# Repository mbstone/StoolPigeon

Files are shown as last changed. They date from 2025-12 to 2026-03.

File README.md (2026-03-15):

# Stool Pigeon
Welcome to the workspace for the open-source project Stool Pigeon. The goal of this project is to create a toilet-mounted device that visually, audibly, and or otherwise monitors bowel movements. 

# Values
* Accessibility 
* Privacy  
* Affordability
* Community 

# What this project needs
* 3D case design
* Board and perpheral design
* Ideas and enthusiasm
* Open-source experience

# What is here
* Some prototype Arduino IDE configuations
* A logging web server used to collect data from device while running and testing
* The Platform IO project used to build the device 
* Some unfinished 3D case designs originally made in Tinkercad

# Project Status
## Progress
* circuit design for basic FSR usage
* connected to wifi
* connected to logging webserver on laptop
* deep sleep woken by button press

## To Do Next
* document hardware layout
* guide for wifi credential deps
* add in image to POST request
* wake from deep sleep with pressure
* add TLS / https

## Future Improvements

## Prototype Picture

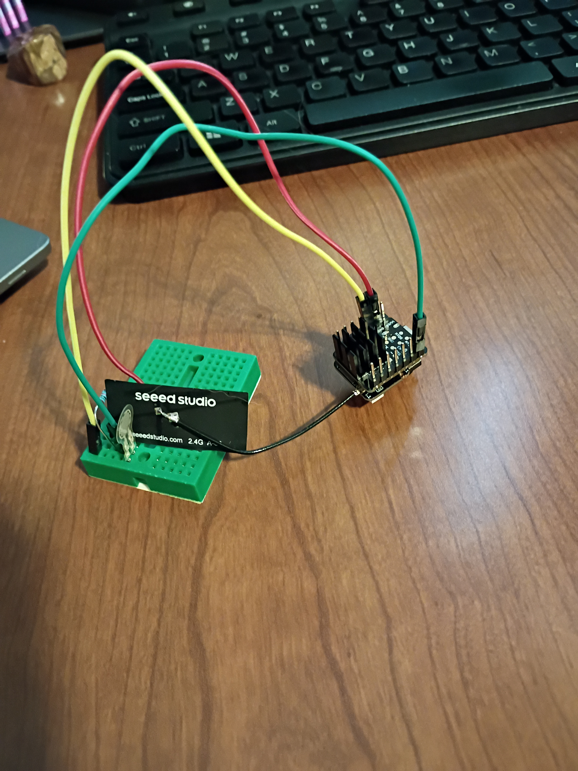
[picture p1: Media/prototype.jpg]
PrototypeSystem


# Notes

## Sketch Uploads
* Correct port only appears after device is plugged in
* open serial monitor manually

## verify / compile errors
* need to install and select XIAO board (SenseS3)

## Force Sensitive Resistors
* Use touch pin to wake
* take reading from FSR to determine seated time and person's identity

## Wifi
* 2.4 Ghz only

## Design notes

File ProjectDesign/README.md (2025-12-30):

# Outerwear
## options
* hanger
* toilet seat
## current selection
* hanger: 
    * strengths: small, no install
    * weakness: physical stability, cleaning
## needs
* allows pressure sensing
* clean easily, brush ideally
* non-invasive
* easy to place and remove
* water-tight
* reasonably priced
* vantage point on bowl

# illumination
## options
* white light LED 
* 500 nm LED with 520-550 emission filter for stool and 600-700 filter for blood
## current selection
* white light LED
    * strengths: cheap, easy hardware, lowest power, presence of training images
    * weakness: detecting blood in edge cases; discrimination of blood and stool
## needs
* bright, stable light source

# network
## options
* toilet device broadcast wifi network, serves images to front end 
* separate server collects images from toilet device client, front end accesses server
## current selection 
* separate server
    * strengths: storage and power, easier to secure, supports multiple users, easier to send data to iPoop central
    * weakness: additional expense, setup overhead, troubleshooting
## needs
* secure
* store data indefinitely
* support analyses of data
* passive data logging and access 

# stool classification algorithm
## options
* MobileNetV2 
* MCUNetV2
## articles
* https://proceedings.mlr.press/v149/zhou21a/zhou21a.pdf
* https://openaccess.thecvf.com/content/CVPR2022W/CVPM/papers/Zhang_Human_Stools_Classification_for_Gastrointestinal_Health_Based_on_an_Improved_CVPRW_2022_paper.pdf
* https://pmc.ncbi.nlm.nih.gov/articles/PMC11350077/

# electronics
## boards
* Seeed Studio XIAO ESP32S3 Sense
    * 102010635-FA
    * OV2640 camera sensor
    * https://wiki.seeedstudio.com/xiao_esp32s3_getting_started/
    * https://mjrovai.github.io/XIAO_Big_Power_Small_Board-ebook/
    * camera pins here: https://github.com/limengdu/SeeedStudio-XIAO-ESP32S3-Sense-camera/blob/main/take_photos/camera_pins.h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
    * core: 
        * ESP32-S3R8
        * Xtensa LX7 dual-core, 32-bit processor up to 240 MHz
* Ardiuno feather huzzah

# system
## webserver
* plugged in
* receives logs from monitor
* serves logs to personal device app
* runs classification models? 
## monitor
* on battery
* deep sleep during inactivity
## personal device
* checks for new data from webserver
* pulls data onto device
* runs classification models?

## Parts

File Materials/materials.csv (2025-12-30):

Product Name | Manufacturer | Purchase Amount | Source | URL | Last Purchased Date | Purpose | Manufacturer ID
Seeed Studio XIAO ESP32S3 Sense (Pre-Soldered) | Seeed Studio | $24.99 | Amazon | https://www.amazon.com/dp/B0DRNW6KMG?ref=ppx_pop_dt_b_product_details&th=1 | Jan 25, 2025 | Toilet-mounted control board with camera, mic, and wifi | 102010635
Thin Film Pressure Sensor | Flexniss | $8.74 | Amazon | https://www.amazon.com/dp/B07T1CHY58?psc=1&ref=ppx_pop_dt_b_product_details | Jan 6, 2025 | Detection of seated user on toilet | DF9-16

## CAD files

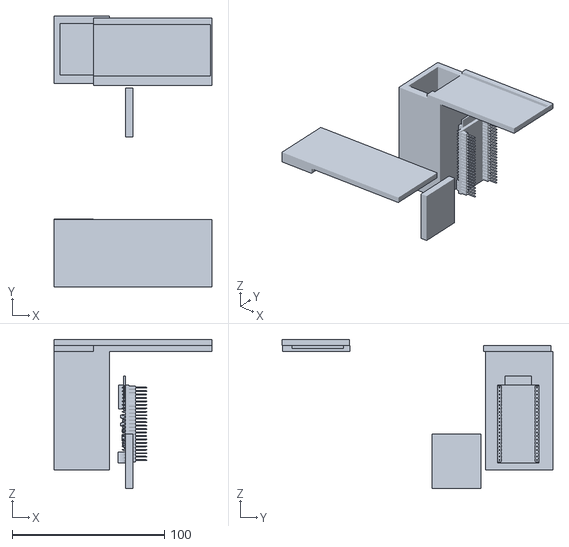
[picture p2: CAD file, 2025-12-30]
CaseDesign/ESP32 S3 Hanging Mount.stl
103.7 x 177.8 x 98.0

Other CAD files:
CaseDesign/ESP32 S3 Hanging Mount/tinker.obj

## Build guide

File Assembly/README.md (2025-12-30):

# Assembly details

## Monitoring board prototype
* XIAO ESP32 Sense S3 presoldered board was prepared by mounting heat sync to underside
* breadboard and breadboarding wires used to prototype connections as shown
* Thin film force sensor is connected to ESP32 board pin D0 with 10k Ohm resistor 
    * 3V3 pin on S3 to force sensor
    * force sensor to D0 pin on S3 (parallel)
    * (parallel) to 10k Ohms resistor
    * 10k Ohms resistor to GND pin on S3 

### Breadboard
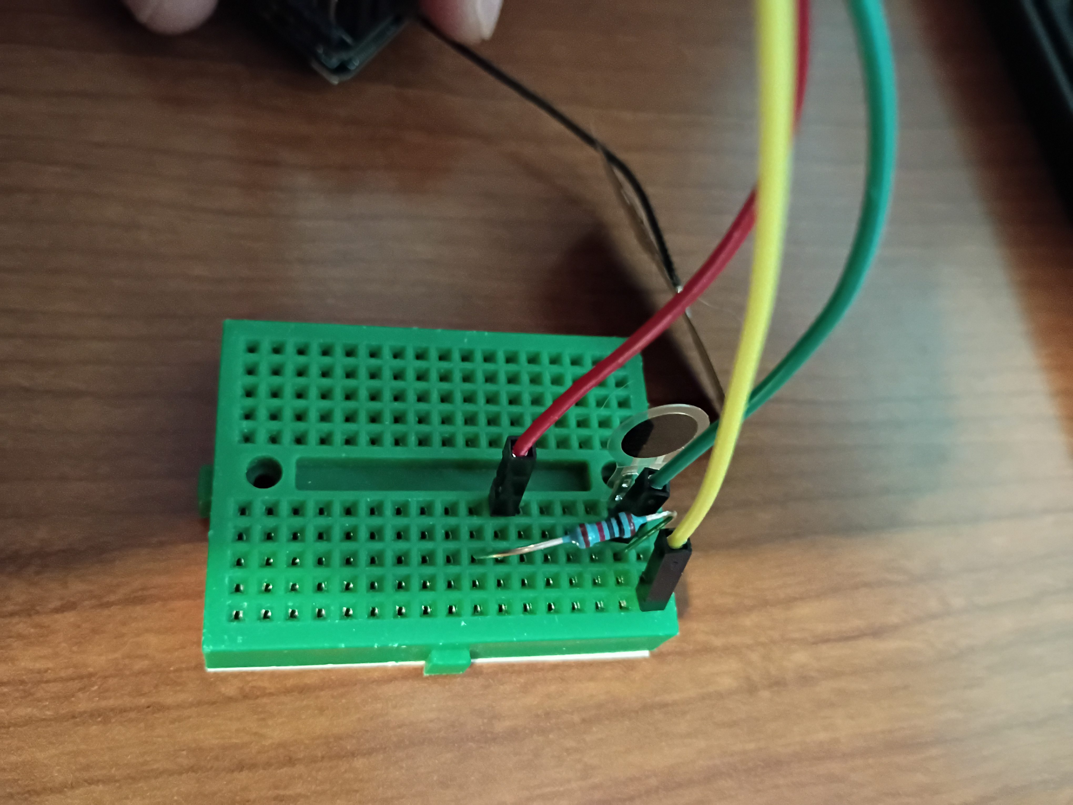
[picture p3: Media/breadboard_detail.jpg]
BreadboardDetail


### Sense S3
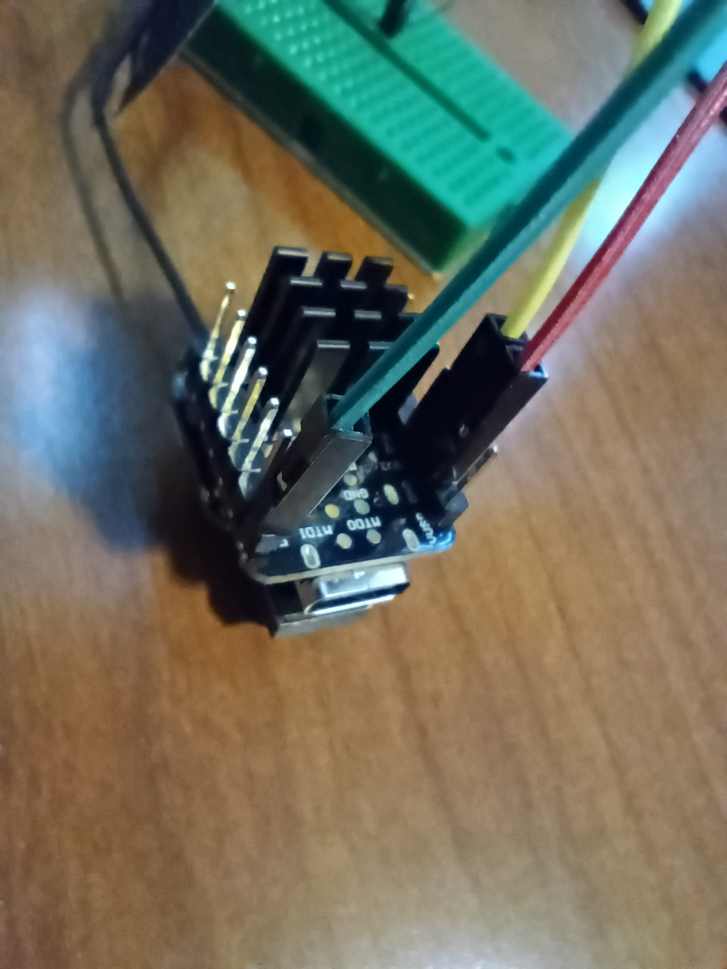
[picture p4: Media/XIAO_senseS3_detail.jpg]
SenseS3Detail


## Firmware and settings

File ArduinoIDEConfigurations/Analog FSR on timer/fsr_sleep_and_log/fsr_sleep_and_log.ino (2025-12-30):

#include <WiFi.h>
#include <HTTPClient.h>
#include <WifiCredentials.h>
#include <WebServerDetails.h>

#define FSR_PIN A0
#define R_FIXED 10000.0               // 10kΩ resistor in voltage divider
#define FSR_THRESHOLD 1200           // Below this = no pressure
#define SLEEP_DELAY_US 10e6          // Sleep for 10 seconds (microseconds)

unsigned long lastHighPressureTime = 0;
const unsigned long PRESSURE_HOLD_MS = 5000;  // 5 seconds

void setup() {
  Serial.begin(115200);
  while (!Serial);
  delay(500);

  Serial.println("ESP32 Wake with FSR and Wi-Fi HTTP Logging Test");

  printWakeReason();

  // Connect to Wi-Fi
  WiFi.begin(WIFI_SSID, WIFI_PASSWORD);
  Serial.print("Connecting to Wi-Fi");
  while (WiFi.status() != WL_CONNECTED) {
    delay(500);
    Serial.print(".");
  }
  Serial.println("\nWi-Fi connected!");
  Serial.print("ESP32 IP Address: ");
  Serial.println(WiFi.localIP());

  // Read initial FSR value
  int fsr = analogRead(FSR_PIN);
  float voltage = (fsr / 4095.0) * 3.3;
  float resistance = (R_FIXED * (3.3 - voltage)) / voltage;
  Serial.print("Initial FSR Reading: ");
  Serial.println(fsr);  

  char queryParams[30]
  sprintf(queryParams, "fsr=%d&voltage=%1.1&resistance=%4.0", voltage)

  // log values to webserver
  String url = String("http://") + SERVER_HOST + ":" + SERVER_PORT +
               String("/log?") + queryParams;

  if (fsr < FSR_THRESHOLD) {
    Serial.println("No pressure detected. Going back to sleep...");
    pinMode(LED_BUILTIN, OUTPUT);
    digitalWrite(LED_BUILTIN, HIGH); // Turn on before sleep
    delay(3000);  // helps to see light
    esp_sleep_enable_timer_wakeup(SLEEP_DELAY_US);
    esp_deep_sleep_start();
  } else {
    Serial.println("Pressure detected! Staying awake...");
    lastHighPressureTime = millis();  // Start tracking
  }
}

void loop() {
  pinMode(LED_BUILTIN, OUTPUT);
  digitalWrite(LED_BUILTIN, HIGH); // Turn on before sleep  
  int fsr = analogRead(FSR_PIN);
  float voltage = (fsr / 4095.0) * 3.3;
  float resistance = (R_FIXED * (3.3 - voltage)) / voltage;

  Serial.print("Analog: ");
  Serial.print(fsr);
  Serial.print(" | Voltage: ");
  Serial.print(voltage, 3);
  Serial.print(" V | FSR Resistance: ");
  Serial.print(resistance, 1);
  Serial.println(" ohms");

  if (fsr >= FSR_THRESHOLD) {
    lastHighPressureTime = millis();  // Reset timer if pressure continues
  }

  // If pressure has been low for 5 seconds, go back to sleep
  if (millis() - lastHighPressureTime > PRESSURE_HOLD_MS) {
    Serial.println("Pressure released. Sleeping in 3 seconds ...");
    delay(3000);  // Let message flush    
    esp_sleep_enable_timer_wakeup(SLEEP_DELAY_US);
    esp_deep_sleep_start();
  }

  delay(500);  // Sample interval
}

void printWakeReason() {
  esp_sleep_wakeup_cause_t cause = esp_sleep_get_wakeup_cause();
  switch (cause) {
    case ESP_SLEEP_WAKEUP_TIMER:
      Serial.println("Wakeup from timer.");
      break;
    case ESP_SLEEP_WAKEUP_UNDEFINED:
      Serial.println("Normal power-on boot.");
      break;
    default:
      Serial.printf("Wakeup cause: %d\n", cause);
      break;
  }
}

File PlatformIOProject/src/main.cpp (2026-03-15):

#include <Arduino.h>
#include <WiFi.h>
#include <HTTPClient.h>
#include <WifiCredentials.h>
#include <WebServerDetails.h>
#include <driver/rtc_io.h>
#include <ArduinoJson.h>

#define FSR_PIN A0           // Analog pin connected to the divider
#define R_FIXED 10000.0      // Fixed resistor value in ohms (10k)
#define FSR_THRESHOLD 1200           // Below this = no pressure
#define SLEEP_DELAY_US 10e6          // Sleep for 10 seconds (microseconds)
#define WAKEUP_GPIO  GPIO_NUM_2

// set variable for tracking last time high pressure observed 
unsigned long lastHighPressureTime = 0;
// set max allowed dead time without high pressure
const unsigned long PRESSURE_HOLD_MS = 30000;  // 30 seconds
// Build startup URL
String url = String("http://") + SERVER_HOST + ":" + SERVER_PORT + "/log";
// Initialize http client
HTTPClient http;
// Allocate the JSON document
JsonDocument doc;
// Initialize JsonBuffer
String jsonBuffer;
// Image constants
#define EI_CAMERA_RAW_FRAME_BUFFER_COLS           320
#define EI_CAMERA_RAW_FRAME_BUFFER_ROWS           240
#define EI_CAMERA_FRAME_BYTE_SIZE                 3

void setup() {
  Serial.begin(115200);
  delay(500);
  Serial.println("ESP32 Wi-Fi HTTP Logging Test");

  // Connect to Wi-Fi
  WiFi.begin(WIFI_SSID, WIFI_PASSWORD);
  Serial.print("Connecting to Wi-Fi");
  while (WiFi.status() != WL_CONNECTED) {
    delay(500);
    Serial.print(".");
  }
  Serial.println("\nWi-Fi connected!");
  Serial.print("ESP32 IP Address: ");
  Serial.println(WiFi.localIP());


  http.begin(url);
  Serial.println("Sending POST request to:");
  Serial.println(url);

  // fill the json document
  doc["fsr"] = 0;
  doc["voltage"] = 0.0;
  doc["resistance"] = 0.0;
  doc["message"] = "Stool Pigeon starting up";

  // 2. Serialize JSON to a string
  serializeJson(doc, jsonBuffer); // serializeJson() produces minified JSON output
  http.addHeader("Content-Type", "application/json");

  int httpCode = http.POST(jsonBuffer);
  if (httpCode > 0) {
    Serial.printf("HTTP Response Code: %d\n", httpCode);
    String payload = http.getString();
    Serial.println("Response:");
    Serial.println(payload);
  } else {
    Serial.printf("Request failed, error: %s\n", http.errorToString(httpCode).c_str());
  }

  http.end();

}

void loop() {
  delay(1000); // Wait before next reading
  int analogValue = analogRead(FSR_PIN);   // 12-bit ADC (0–4095)
  float voltage = (analogValue / 4095.0) * 3.3;  // Convert to volts

  // Calculate FSR resistance using voltage divider formula:
  // Vout = Vcc * R_fixed / (R_fixed + R_fsr)
  // Rearranged: R_fsr = (R_fixed * (Vcc - Vout)) / Vout
  float fsrResistance = (R_FIXED * (3.3 - voltage)) / voltage;

  if (analogValue >= FSR_THRESHOLD) {
    lastHighPressureTime = millis();  // Reset timer if pressure continues
  }

  // If pressure has been low for 5 seconds, go back to sleep for 10 seconds
  if (millis() - lastHighPressureTime > PRESSURE_HOLD_MS) {
    Serial.println("Pressure released. Sleeping in 3 seconds ..."); 
    // esp_sleep_enable_timer_wakeup(SLEEP_DELAY_US);
    esp_sleep_enable_ext0_wakeup(WAKEUP_GPIO, 1);
    esp_deep_sleep_start();
  }  


  // fill the json document
  doc["fsr"] = analogValue;
  doc["voltage"] = voltage;
  doc["resistance"] = fsrResistance;
  doc["message"] = "Mesurement";

  // post request time
  http.begin(url);
  Serial.println("Sending POST request to:");
  Serial.println(url);


  // 2. Serialize JSON to a string
  serializeJson(doc, jsonBuffer); // serializeJson() produces minified JSON output
  http.addHeader("Content-Type", "application/json");

  int httpCode = http.POST(jsonBuffer);
  if (httpCode > 0) {
    Serial.printf("HTTP Response Code: %d\n", httpCode);
    String payload = http.getString();
    Serial.println("Response:");
    Serial.println(payload);
  } else {
    Serial.printf("Request failed, error: %s\n", http.errorToString(httpCode).c_str());
  }

  http.end(); 
}

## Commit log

2025-12-30 added materials and media
    [materials.csv]
2026-02-22 working deep sleep wake on button press
2026-02-22 sensor POSTing measurements instead of GET
2026-03-15 switched main to cpp file
